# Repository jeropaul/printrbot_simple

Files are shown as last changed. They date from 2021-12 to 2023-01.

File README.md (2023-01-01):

# Printrbot Simple Metal
I purchased this printer in 2015 with the heated bed option.

Notes: Aluminium heated bed has quite a few high and low spots > 2 tenths of a mm out. So I print first layer at 0.3 of a mm.

## Board 

currently a Rev F printerbot board. Updated to Marlin 2.0.x using the details at jdwallace.com

Useful links:
- Board details - http://domoticx.com/mechanica-hardware-printrboard/
- Updating firmware 
  - https://www.jdwallace.com/post/printrbot-simple-metal-marlin2
  - https://github.com/Printrbot/Adaptrboard (note adaptrboard is a defunct project)
- Updating to an SKR board
  - https://github.com/Lob0426/Adaptrboard/wiki

## Power supply

[Currently using a semi-modular power supply](https://www.amazon.com.au/gp/product/B08BX65LVY/ref=ppx_yo_dt_b_asin_title_o05_s00?ie=UTF8&psc=1) being honest I probably should have forked out and purchased a fully modular power supply but this works.

I haven't manually jumped the power supply to get it to start as I have an [ATX breakout board](https://www.kickstarter.com/projects/141080940/atx-breakout-board-for-all-pc-power-supplys?ref=profile_created) that I purchased through kickstarter. 

## Heated bed / Build plate

Currently using the Printrbot supplied heated bed. However I have read good things about some of the removable build plates and have a [150x150 Spring Steel Sheet Build Plate](https://www.aliexpress.com/snapshot/0.html?orderId=8143475876268766) on order and I'm hoping to mount this on top of the existing bed.

Note: kapton tape was the rage when I started printing and it was crap... so crap. I'm using buildtak at the moment and life is better.

## Z axis 

Replaced with a 4 stop 8mm lead screw, currently using the details at https://github.com/MS3FGX/PBSM_ZNUT however I like the remix at https://www.thingiverse.com/thing:2843592/files prior to this change I had obvious z-banding so it has been a nice update.

Other options of note: https://www.thingiverse.com/thing:2010572

## Hotend 

I've swtiched over to the UBIS 13s from the original UBIS 13 ceramic. Good things so far and enough new tips to last for (hopefully) many years.

New fan for the hotend has been installed see [Installing automatic hotend](https://github.com/jeropaul/printrbot_simple/issues/1) for details.

useful links:
- Installing an automatic fan 
  - https://www.jdwallace.com/post/printrbot-fan
  - https://www.thingiverse.com/thing:559657
  - https://github.com/tormentist/Marlin/releases/tag/RevF-Version-5_E3Dv6
- Fan adapter for ubis 13s - https://www.youmagine.com/designs/printrbot-hot-end-fan

## Calibration guide for hotends height from bed

The magnetic base and (or) the spring steel pei sheet messes with the bed probe so I had to massively change the z calibration.

Note: These are for Marlin 2.0 

M501 - Load / print config

M851 - Z-2.2  (that was -0.6... so quite a difference)

M500 - Save config

## Drivers for the WIFI dongle (rtl8188eu)

So it looks like the gentleman that maintained http://downloads.fars-robotics.net/ gave up the ghost in late 2021 so no more pre-built drivers! good run though, amazing that he kept it up for something like 10 years. The internet is kept working on the back of people like that.

Anyway to build it from source use the details at https://github.com/RPi-Distro/rpi-source#tp-link-tl-wn725n-version-2-lwfinger

And as always be prepared to wait... 

Than I needed to change the driver used by wpa_supplicant (I had to find that from [stack-exchange](https://raspberrypi.stackexchange.com/questions/116657/raspberry-pi-wifi-scan-working-but-cannot-connect-to-wifi)

```
sudo wpa_supplicant -i wlan0 -D wext -c /etc/wpa_supplicant/wpa_supplicant.conf -d
```

So to make this permanent we need to add the following to `/etc/dhcpcd.conf`

```
env ifwireless=1
env wpa_supplicant_driver=wext
```

## Project information

- How to design an automata - https://www.instructables.com/Design-of-Automata/

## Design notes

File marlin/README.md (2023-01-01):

# Marlin configuration

The hex file here is for a simple metal (152x152x152) with heated bed and an 8mm z-axis.  It also includes the auto-fan for when I upgrade from the Ubis 13 to 13s.

The folder 2.0.9.3 contains configuration files downloaded from https://github.com/MarlinFirmware/Marlin/tree/2.0.9.3/Marlin

This folder contains configuration files originally downloaded from https://github.com/Printrbot/printrboardmodernmarlin/releases which are based on the 2.0.1 

I built the Configuration.h and Configuration_adv.h by diffing the 2.0.1 files with the reference 2.0.9.3 files and manually applying the changes. You can diff the files here to see what changed. The hex file was then built using the vscode marlin plugin.

UPDATE: the hex file for the bugfix-2.0.x branch has been moved into that folder.  This is the pattern I'll run with moving forward.  

## Loading firmware

Easiest on a windows computer but there is a guide on the reprap forums https://reprap.org/wiki/Printrboard that links to github.com/Printrbot/FirmwareUpdat which doesn't exist but I did find http://mickbalaban.github.io/printrbot-firmware-updater/ which downloads the following http://github.com/mickbalaban/printrbot-firmware-updater/raw/gh-pages/pbFU_mac.zip

Yeah it sits there trying to download the latest firmware... Safe bet that path is not possible anymore.

So best bet is to get a winblows PC, install the Atmel updater (and JVM) and do it there. The details at [www.jdwallace.com](https://www.jdwallace.com/post/printrbot-simple-metal-marlin2) are spot on.

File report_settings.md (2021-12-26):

# Report settings (M503 - Stock REV F firmware - 26 DEC 2021)

```
>>> M503
SENDING:M503
echo:Steps per unit:
echo:  M92 X80.00 Y80.00 Z400.00 E96.00
echo:Maximum feedrates (mm/s):
echo:  M203 X125.00 Y125.00 Z5.00 E14.00
echo:Maximum Acceleration (mm/s2):
echo:  M201 X2000 Y2000 Z30 E10000
echo:Acceleration: S=acceleration, T=retract acceleration
echo:  M204 S3000.00 T3000.00
echo:Advanced variables: S=Min feedrate (mm/s), T=Min travel feedrate (mm/s), B=minimum segment time (ms), X=maximum XY jerk (mm/s),  Z=maximum Z jerk (mm/s),  E=maximum E jerk (mm/s)
echo:  M205 S0.00 T0.00 B20000 X20.00 Z0.40 E5.00
echo:Home offset (mm):
echo:  M206 X0.00 Y0.00 Z0.00
echo:PID settings:
echo:   M301 P22.20 I1.08 D114.00
echo:Min position (mm):
echo:  M210 X0.00 Y0.00 Z0.00
echo:Max position (mm):
echo:  M211 X152.40 Y152.40 Z152.40
echo:Bed probe offset (mm):
echo:  M212 X0.00 Y0.00 Z-0.75
Disconnected.
```

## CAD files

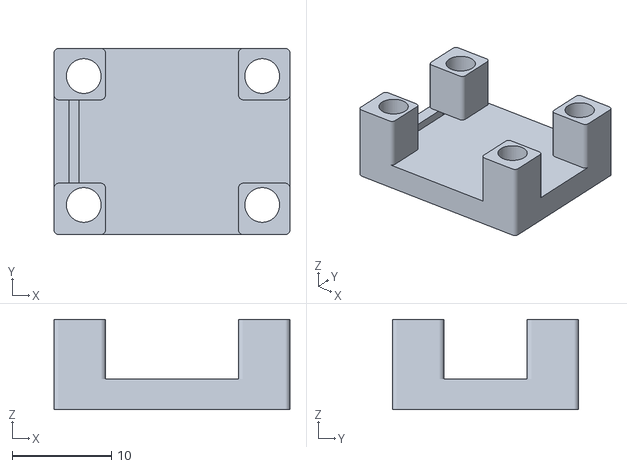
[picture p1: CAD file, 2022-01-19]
ndrive/holder.stl
23.8 x 18.8 x 9.10

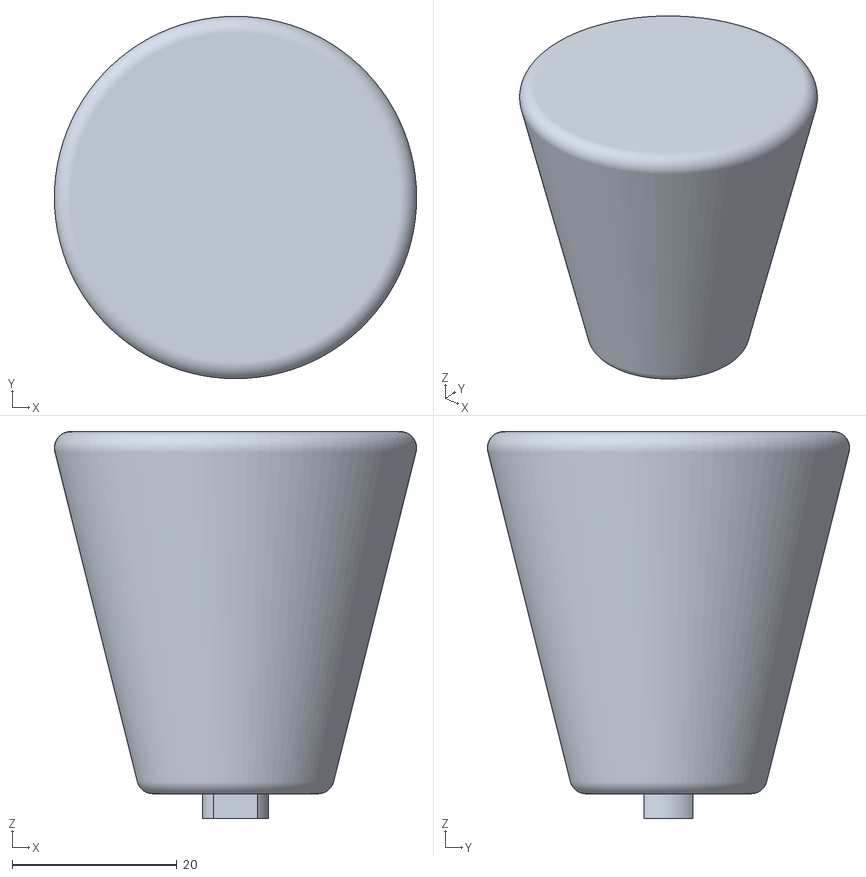
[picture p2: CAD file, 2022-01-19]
speed_heater/blade_holder.stl
44.0 x 44.0 x 47.0

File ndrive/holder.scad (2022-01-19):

$fn=50;

module base() {
  union () { 
    minkowski() {
      cube([22.8 , 17.8, 3]);
      cylinder(h=0.1, d=1);
    }

    minkowski() {
      translate([0,0,0]) cube([4.2,4.2,9]);
      cylinder(h=0.1, d=1);
    }
    minkowski() {
     translate([0,13.6,0]) cube([4.2,4.2,9]);
     cylinder(h=0.1, d=1);
    }
    minkowski() {
     translate([18.6,0,0]) cube([4.2,4.2,9]);
     cylinder(h=0.1, d=1);
    }
    minkowski() {
     translate([18.6,13.6,0]) cube([4.2,4.2,9]);
     cylinder(h=0.1, d=1);
    }
  }  
}

module screws() {
  translate([20.5,15.5,0]) cylinder(h=10, d=3.5);
  translate([2.5,15.5,0]) cylinder(h=10, d=3.5);
  translate([2.5,2.5,0]) cylinder(h=10, d=3.5);
  translate([20.5,2.5,0]) cylinder(h=10, d=3.5);  
}

module pin_holder() {
  translate([1,4,1]) cube([1,10,2.1]);  
}

difference() {
  base();
  screws();
  pin_holder();
}

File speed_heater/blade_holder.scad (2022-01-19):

// Flat edge 6mm
// curve 8mm
// Depth... 4mm
$fn=100;

module pin() {
  pin_height=3;
  difference() {
    cylinder(h=pin_height, d=8);
    translate([-4, 3, 0]) cube([8, 1, pin_height]);
    translate([-4, -4, 0]) cube([8, 1, pin_height]);
  }
}

pin();
minkowski() { 
  translate([0,0,5]) cylinder(h=40, r1=10, r2=20);  
  sphere(d=4);
}

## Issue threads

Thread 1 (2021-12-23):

Automatic fan for hotend

jeropaul, 2021-12-23:
I'll follow the details laid out at https://www.jdwallace.com/post/printrbot-fan

Mosfet - https://www.freetronics.com.au/products/n-mosfet-driver-output-module#.YcRkkPFBzu0

I'll need to crimp some wires and I'll need to solder some header pins onto this module. So
I'll grab something like https://www.amazon.com.au/dp/B093B47HCT?psc=1&smid=A19W1DLKYS7GUQ&ref_=chk_typ_imgToDp

Now to figure out where my soldering iron is

jeropaul, 2022-01-15:
I'm stuck working on this stuff outside and I only really get the chance when my little person is sleeping.  Anyway I finally managed to get a few mins to work on this and soldered some pins onto the NDrive.  Which I think came out okay but I'm obviously an amateur at soldering and I can't find my multi-meter to confirm...

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

Next step is going be wiring this upto the board...

jeropaul, 2022-01-16:
So I've just rigged this up into a test configuration to check that it is working before finishing wiring this up and all looking good so far!  Fan turns on at 50º Celsius and off when it drops below that.

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

now to figure out a more permanent solution to getting +12 and ground onto the fan....

jeropaul, 2022-01-19:
Finished wiring up the fan! the [clips I used are a little chunky](https://www.amazon.com.au/gp/product/B09HH2Y9CK/ref=ppx_yo_dt_b_asin_title_o02_s00?ie=UTF8&psc=1) but work well enough.  Thankfully there is a lot of space under there.

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

jeropaul, 2022-01-19:
So this is now done. I'll install the ubis 13s on the weekend

Closed 2022-01-19.

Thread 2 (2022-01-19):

Install the ubis 13s hotend.

jeropaul, 2022-01-19:
Title says it all.  We now have a fan (see #1) so lets get the ubis 13s installed.

jeropaul, 2022-02-06:
I finished installing the new hotend works well

![Uploading new_hotend.jpg…]()

Closed 2022-02-06.

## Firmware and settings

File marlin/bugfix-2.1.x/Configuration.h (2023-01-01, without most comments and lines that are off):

#pragma once
#define CONFIGURATION_H_VERSION 02010200
#define STRING_CONFIG_H_AUTHOR "(Jerome Paul)" // Who made the changes.
  #define MOTHERBOARD BOARD_PRINTRBOARD_REVF
#define SERIAL_PORT 0
#define BAUDRATE 250000
#define CUSTOM_MACHINE_NAME "Printrbot Simple Metal"
#define MACHINE_UUID "ffad5ec8-1933-41d6-a241-f902ff41b256"
#define X_DRIVER_TYPE  A4988
#define Y_DRIVER_TYPE  A4988
#define Z_DRIVER_TYPE  A4988
#define E0_DRIVER_TYPE A4988
#define EXTRUDERS 1
#define DEFAULT_NOMINAL_FILAMENT_DIA 1.75
#define TEMP_SENSOR_0 1
#define TEMP_SENSOR_1 0
#define TEMP_SENSOR_2 0
#define TEMP_SENSOR_3 0
#define TEMP_SENSOR_4 0
#define TEMP_SENSOR_5 0
#define TEMP_SENSOR_6 0
#define TEMP_SENSOR_7 0
#define TEMP_SENSOR_BED 7
#define TEMP_SENSOR_PROBE 0
#define TEMP_SENSOR_CHAMBER 0
#define TEMP_SENSOR_COOLER 0
#define TEMP_SENSOR_BOARD 0
#define TEMP_SENSOR_REDUNDANT 0
#define DUMMY_THERMISTOR_998_VALUE  25
#define DUMMY_THERMISTOR_999_VALUE 100
#if TEMP_SENSOR_IS_MAX_TC(0)
  #define MAX31865_SENSOR_OHMS_0      100 // (Ω) Typically 100 or 1000 (PT100 or PT1000)
  #define MAX31865_CALIBRATION_OHMS_0 430 // (Ω) Typically 430 for Adafruit PT100; 4300 for Adafruit PT1000
#endif
#if TEMP_SENSOR_IS_MAX_TC(1)
  #define MAX31865_SENSOR_OHMS_1      100
  #define MAX31865_CALIBRATION_OHMS_1 430
#endif
#if TEMP_SENSOR_IS_MAX_TC(2)
  #define MAX31865_SENSOR_OHMS_2      100
  #define MAX31865_CALIBRATION_OHMS_2 430
#endif
#if HAS_E_TEMP_SENSOR
  #define TEMP_RESIDENCY_TIME         10  // (seconds) Time to wait for hotend to "settle" in M109
  #define TEMP_WINDOW                  1  // (°C) Temperature proximity for the "temperature reached" timer
  #define TEMP_HYSTERESIS              3  // (°C) Temperature proximity considered "close enough" to the target
#endif
#if TEMP_SENSOR_BED
  #define TEMP_BED_RESIDENCY_TIME     10  // (seconds) Time to wait for bed to "settle" in M190
  #define TEMP_BED_WINDOW              1  // (°C) Temperature proximity for the "temperature reached" timer
  #define TEMP_BED_HYSTERESIS          3  // (°C) Temperature proximity considered "close enough" to the target
#endif
#if TEMP_SENSOR_CHAMBER
  #define TEMP_CHAMBER_RESIDENCY_TIME 10  // (seconds) Time to wait for chamber to "settle" in M191
  #define TEMP_CHAMBER_WINDOW          1  // (°C) Temperature proximity for the "temperature reached" timer
  #define TEMP_CHAMBER_HYSTERESIS      3  // (°C) Temperature proximity considered "close enough" to the target
#endif
#if TEMP_SENSOR_REDUNDANT
  #define TEMP_SENSOR_REDUNDANT_SOURCE    E1  // The sensor that will provide the redundant reading.
  #define TEMP_SENSOR_REDUNDANT_TARGET    E0  // The sensor that we are providing a redundant reading for.
  #define TEMP_SENSOR_REDUNDANT_MAX_DIFF  10  // (°C) Temperature difference that will trigger a print abort.
#endif
#define HEATER_0_MINTEMP   5
#define HEATER_1_MINTEMP   5
#define HEATER_2_MINTEMP   5
#define HEATER_3_MINTEMP   5
#define HEATER_4_MINTEMP   5
#define HEATER_5_MINTEMP   5
#define HEATER_6_MINTEMP   5
#define HEATER_7_MINTEMP   5
#define BED_MINTEMP        5
#define CHAMBER_MINTEMP    5
#define HEATER_0_MAXTEMP 275
#define HEATER_1_MAXTEMP 275
#define HEATER_2_MAXTEMP 275
#define HEATER_3_MAXTEMP 275
#define HEATER_4_MAXTEMP 275
#define HEATER_5_MAXTEMP 275
#define HEATER_6_MAXTEMP 275
#define HEATER_7_MAXTEMP 275
#define BED_MAXTEMP      150
#define CHAMBER_MAXTEMP  60
#define HOTEND_OVERSHOOT 15   // (°C) Forbid temperatures over MAXTEMP - OVERSHOOT
#define BED_OVERSHOOT    10   // (°C) Forbid temperatures over MAXTEMP - OVERSHOOT
#define COOLER_OVERSHOOT  2   // (°C) Forbid temperatures closer than OVERSHOOT
#define PIDTEMP          // See the PID Tuning Guide at https://reprap.org/wiki/PID_Tuning
#define BANG_MAX 255     // Limits current to nozzle while in bang-bang mode; 255=full current
#define PID_MAX BANG_MAX // Limits current to nozzle while PID is active (see PID_FUNCTIONAL_RANGE below); 255=full current
#define PID_K1 0.95      // Smoothing factor within any PID loop
    #define DEFAULT_Kp  63.53
    #define DEFAULT_Ki   8.16
    #define DEFAULT_Kd 123.60
#define PIDTEMPBED
#define MAX_BED_POWER 255 // limits duty cycle to bed; 255=full current
  #define DEFAULT_bedKp 125.99
  #define DEFAULT_bedKi 15.69
  #define DEFAULT_bedKd 674.30
#define MAX_CHAMBER_POWER 255 // limits duty cycle to chamber heater; 255=full current
  #define PID_FUNCTIONAL_RANGE 10 // If the temperature difference between the target temperature and the actual temperature
#define PREVENT_COLD_EXTRUSION
#define EXTRUDE_MINTEMP 170
#define PREVENT_LENGTHY_EXTRUDE
#define EXTRUDE_MAXLENGTH 200
#define THERMAL_PROTECTION_HOTENDS // Enable thermal protection for all extruders
#define THERMAL_PROTECTION_BED     // Enable thermal protection for the heated bed
#define THERMAL_PROTECTION_CHAMBER // Enable thermal protection for the heated chamber
#define THERMAL_PROTECTION_COOLER  // Enable thermal protection for the laser cooling
#define USE_XMIN_PLUG
#define USE_ZMIN_PLUG
#define USE_YMAX_PLUG
#define ENDSTOPPULLUPS
#define X_MIN_ENDSTOP_INVERTING false // Set to true to invert the logic of the endstop.
#define Y_MIN_ENDSTOP_INVERTING false // Set to true to invert the logic of the endstop.
#define Z_MIN_ENDSTOP_INVERTING true // Set to true to invert the logic of the endstop.
#define I_MIN_ENDSTOP_INVERTING false // Set to true to invert the logic of the endstop.
#define J_MIN_ENDSTOP_INVERTING false // Set to true to invert the logic of the endstop.
#define K_MIN_ENDSTOP_INVERTING false // Set to true to invert the logic of the endstop.
#define U_MIN_ENDSTOP_INVERTING false // Set to true to invert the logic of the endstop.
#define V_MIN_ENDSTOP_INVERTING false // Set to true to invert the logic of the endstop.
#define W_MIN_ENDSTOP_INVERTING false // Set to true to invert the logic of the endstop.
#define X_MAX_ENDSTOP_INVERTING false // Set to true to invert the logic of the endstop.
#define Y_MAX_ENDSTOP_INVERTING false // Set to true to invert the logic of the endstop.
#define Z_MAX_ENDSTOP_INVERTING false // Set to true to invert the logic of the endstop.
#define I_MAX_ENDSTOP_INVERTING false // Set to true to invert the logic of the endstop.
#define J_MAX_ENDSTOP_INVERTING false // Set to true to invert the logic of the endstop.
#define K_MAX_ENDSTOP_INVERTING false // Set to true to invert the logic of the endstop.
#define U_MAX_ENDSTOP_INVERTING false // Set to true to invert the logic of the endstop.
#define V_MAX_ENDSTOP_INVERTING false // Set to true to invert the logic of the endstop.
#define W_MAX_ENDSTOP_INVERTING false // Set to true to invert the logic of the endstop.
#define Z_MIN_PROBE_ENDSTOP_INVERTING true // Set to true to invert the logic of the probe.
#define DEFAULT_AXIS_STEPS_PER_UNIT   { 80, 80, 400, 96 }
#define DEFAULT_MAX_FEEDRATE          { 125, 125, 5, 14 }
#define DEFAULT_MAX_ACCELERATION      { 3000, 3000, 100, 10000 }
#define DEFAULT_ACCELERATION                  1500  // X, Y, Z ... and E acceleration for printing moves
#define DEFAULT_RETRACT_ACCELERATION          3000  // E acceleration for retracts
#define DEFAULT_TRAVEL_ACCELERATION           1500  // X, Y, Z ... acceleration for travel (non printing) moves
#define CLASSIC_JERK
  #define DEFAULT_XJERK 10.0
  #define DEFAULT_YJERK 10.0
  #define DEFAULT_ZJERK  0.3
#define DEFAULT_EJERK    10  // May be used by Linear Advance
#define Z_MIN_PROBE_USES_Z_MIN_ENDSTOP_PIN
#define FIX_MOUNTED_PROBE
#define NOZZLE_TO_PROBE_OFFSET { 20, 0, 0 }
#define PROBING_MARGIN 10
#define XY_PROBE_FEEDRATE (133*60)
#define Z_PROBE_FEEDRATE_FAST (4*60)
#define Z_PROBE_FEEDRATE_SLOW (Z_PROBE_FEEDRATE_FAST / 2)
#define MULTIPLE_PROBING 2
#define Z_CLEARANCE_DEPLOY_PROBE   10 // Z Clearance for Deploy/Stow
#define Z_CLEARANCE_BETWEEN_PROBES  5 // Z Clearance between probe points
#define Z_CLEARANCE_MULTI_PROBE     5 // Z Clearance between multiple probes
#define Z_PROBE_LOW_POINT          -2 // Farthest distance below the trigger-point to go before stopping
#define Z_PROBE_OFFSET_RANGE_MIN -20
#define Z_PROBE_OFFSET_RANGE_MAX 20
#define X_ENABLE_ON 0
#define Y_ENABLE_ON 0
#define Z_ENABLE_ON 0
#define E_ENABLE_ON 0 // For all extruders
#define DISABLE_X false
#define DISABLE_Y false
#define DISABLE_Z false
#define DISABLE_E false             // Disable the extruder when not stepping
#define DISABLE_INACTIVE_EXTRUDER   // Keep only the active extruder enabled
#define INVERT_X_DIR true
#define INVERT_Y_DIR true
#define INVERT_Z_DIR true
#define INVERT_E0_DIR false
#define INVERT_E1_DIR false
#define INVERT_E2_DIR false
#define INVERT_E3_DIR false
#define INVERT_E4_DIR false
#define INVERT_E5_DIR false
#define INVERT_E6_DIR false
#define INVERT_E7_DIR false
#define Z_HOMING_HEIGHT  3      // (mm) Minimal Z height before homing (G28) for Z clearance above the bed, clamps, ...
#define X_HOME_DIR -1
#define Y_HOME_DIR 1
#define Z_HOME_DIR -1
#define X_BED_SIZE 152
#define Y_BED_SIZE 152
#define X_MIN_POS 0
#define Y_MIN_POS 0
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

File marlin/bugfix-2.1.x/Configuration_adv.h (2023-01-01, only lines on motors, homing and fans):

#define E0_AUTO_FAN_PIN 37
#define E1_AUTO_FAN_PIN -1
#define E2_AUTO_FAN_PIN -1
#define E3_AUTO_FAN_PIN -1
#define E4_AUTO_FAN_PIN -1
#define E5_AUTO_FAN_PIN -1
#define E6_AUTO_FAN_PIN -1
#define E7_AUTO_FAN_PIN -1
#define CHAMBER_AUTO_FAN_PIN -1
#define COOLER_AUTO_FAN_PIN -1
#define COOLER_FAN_PIN -1
#define HOMING_BUMP_MM      { 5, 5, 2 }       // (linear=mm, rotational=°) Backoff from endstops after first bump
#define HOMING_BUMP_DIVISOR { 2, 2, 4 }       // Re-Bump Speed Divisor (Divides the Homing Feedrate)
#define MICROSTEP_MODES { 16, 16, 16, 16, 16, 16 } // [1,2,4,8,16]
#define DAC_MOTOR_CURRENT_DEFAULT { 70, 80, 90, 80 }      // Default drive percent - X, Y, Z, E axis
#define LIN_ADVANCE
    #define ADVANCE_K 0.08        // (mm) Compression length applying to all extruders

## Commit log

2021-12-23 Notes regarding my printrbot
2021-12-26 Retrieve marlin configuration in preparation for updating my printer
    [Configuration.h, Configuration_adv.h]
2021-12-26 Update configuration.h file supplied by drphil3d to marlin 2.0.9.3
    [Configuration.h]
2021-12-26 Update configuration_adv.h file supplied by drphil3d to marlin 2.0.9.3
    [Configuration_adv.h]
2021-12-26 Set the extruder fan to run off pin 37. Documented at 'https://www.jdwallace.com/post/printrbot-fan'
    [Configuration_adv.h]
2021-12-26 Ensure that the heated bed is configured
    [Configuration.h]
2021-12-26 Compiler indicated that a default EJERK >= 10 should be used
    [Configuration.h]
2021-12-26 S curve an liner advance do not play well together according the compiler
    [Configuration.h]
2021-12-26 No LCD installed so removing definition for the advanced pause feature
    [Configuration_adv.h]
2021-12-26 add marlin 2.0.9.3 firmware
2021-12-27 Add baseconfiguration for marlin 2.0.x bugfix branch
    [Configuration.h, Configuration_adv.h]
2021-12-27 Update defaults after running hotend and bed autotune
    [Configuration.h]
2021-12-31 Add a basic holder with solder guide for the ndrive logic plate
    [holder.scad, holder.stl]
2022-01-16 Add notes documenting the marlin configuration.
2022-01-19 tweak the dimensions of the ndrive holder to get the bolt guides to line up
    [holder.scad, holder.stl]
2022-01-19 First attempt to create a gripper / holder for the speedheater blades so I can sharpen them
    [blade_holder.scad, blade_holder.stl]
2022-01-19 link to the issue describing the installation of the hotend fan
2022-02-05 Updates notes regarding hotend in use
2022-03-05 Add some calibration notes for the hotend height
2022-09-24 Add driver details for the wireless dongle
2023-01-01 Add default conf for the bugfix-2.1.x branch
    [Configuration.h, Configuration_adv.h]
2023-01-01 Create printrbot configuration and firmware for marlin 2.1.x
    [Configuration.h, Configuration_adv.h]

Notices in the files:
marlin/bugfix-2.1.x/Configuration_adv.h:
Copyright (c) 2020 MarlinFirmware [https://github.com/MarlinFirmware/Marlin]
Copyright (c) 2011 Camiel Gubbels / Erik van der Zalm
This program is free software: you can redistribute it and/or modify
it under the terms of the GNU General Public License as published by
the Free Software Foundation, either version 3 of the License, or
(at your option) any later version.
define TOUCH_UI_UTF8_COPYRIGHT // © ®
